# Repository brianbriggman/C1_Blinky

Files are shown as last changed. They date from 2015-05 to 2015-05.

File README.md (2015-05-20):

# C1_Blinky

The 'firmware' directory contains the firmware that gets flashed to the ATtiny85.  It can be re-built and re-flashed with a 'make clean' and 'make program'.

The 'commandline' directory contains the 'set-led' executable that sends R G B values to the 'C1_Blinky' connected to the USB port.  It can be re-built with a 'make clean' and 'make'.

Once compiled, you can execute 'set-led' using the format:  
  
	sudo ./set-led 255 0 0  
  
Where the 3 values following the 'set-led' command are the R(ed), G(reen), and B(lue) values respectively.  (The command above sets the C1 Blinky to full intensity red.)

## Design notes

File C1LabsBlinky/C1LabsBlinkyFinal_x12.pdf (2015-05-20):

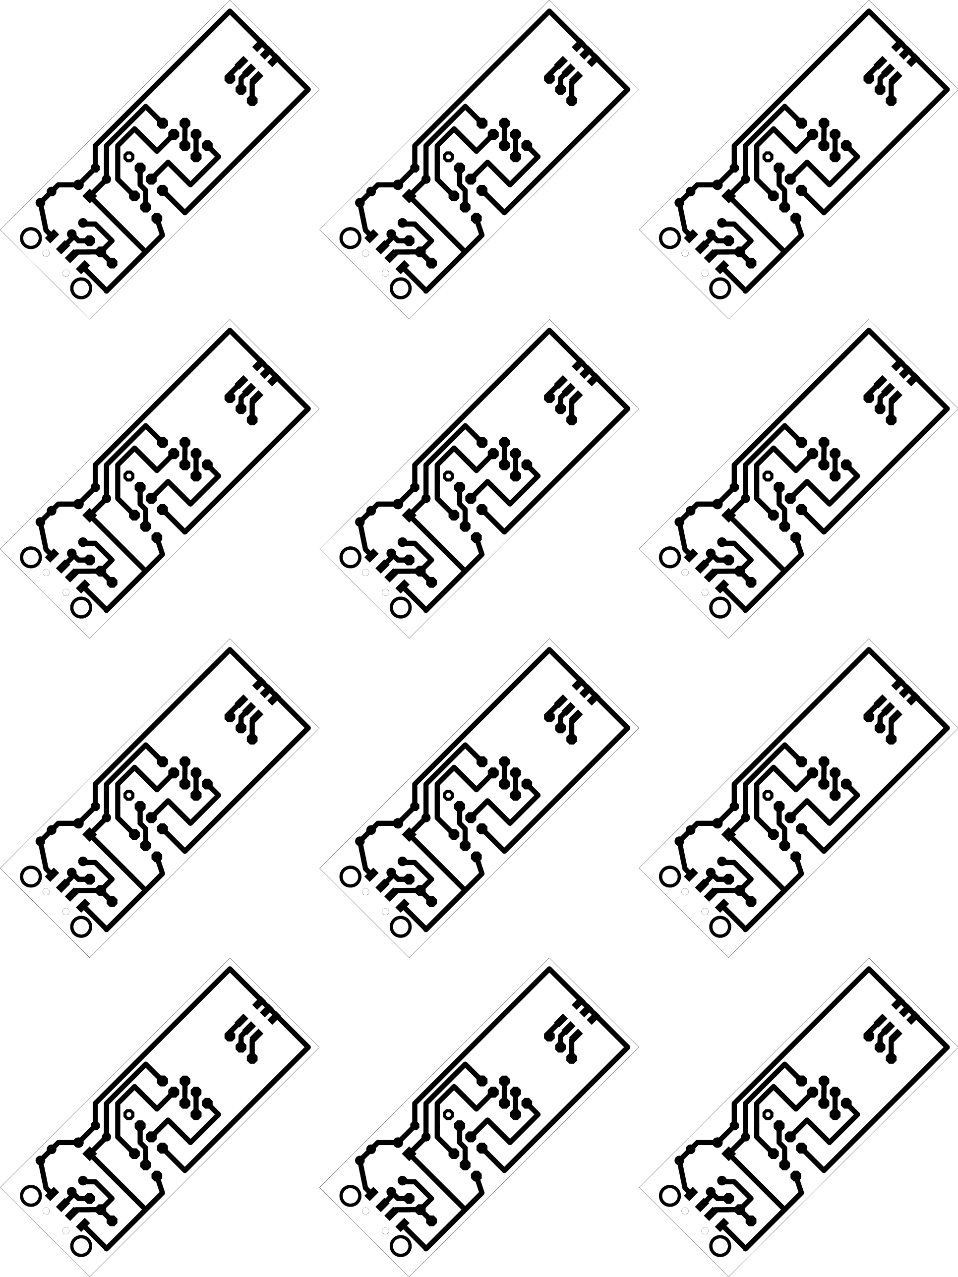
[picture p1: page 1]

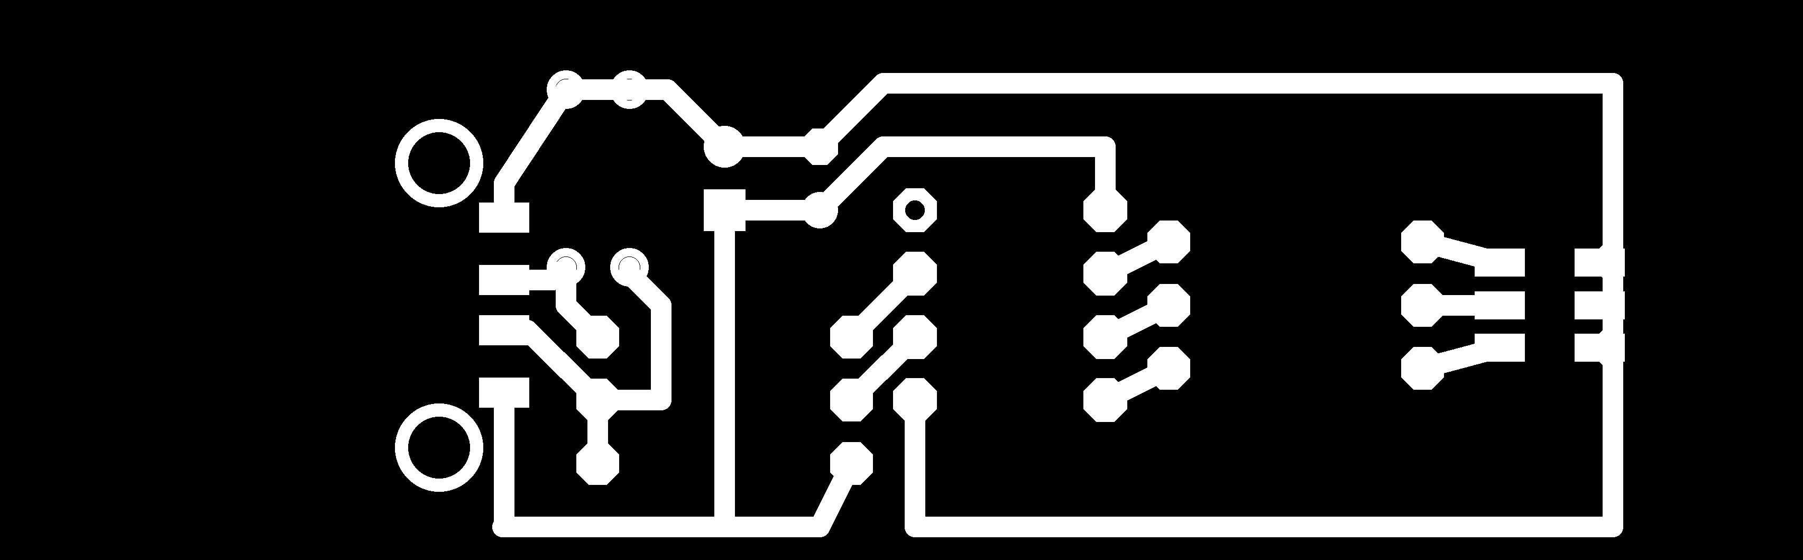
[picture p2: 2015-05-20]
C1LabsBlinky/pcb.png

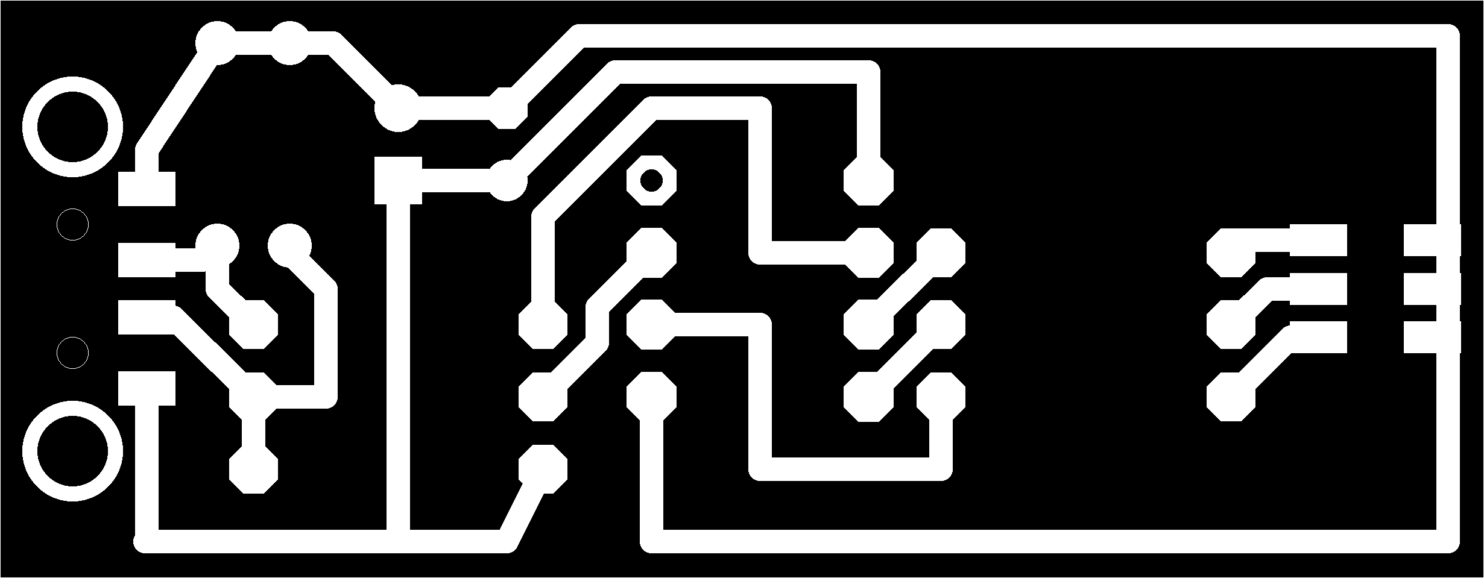
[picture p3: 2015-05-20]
C1LabsBlinky/C1LabsBlinkyFinal_out.png

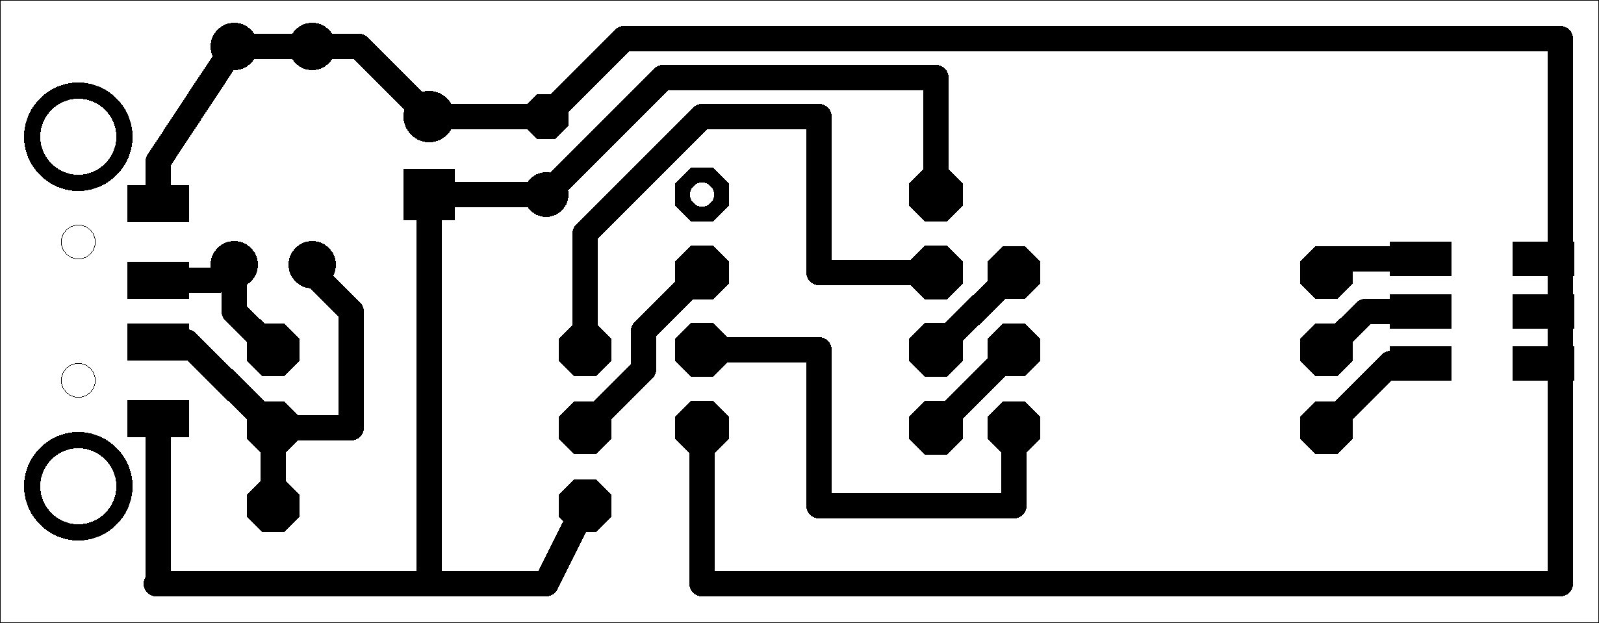
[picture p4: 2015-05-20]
C1LabsBlinky/C1LabsBlinkyFinal_out_pos.png

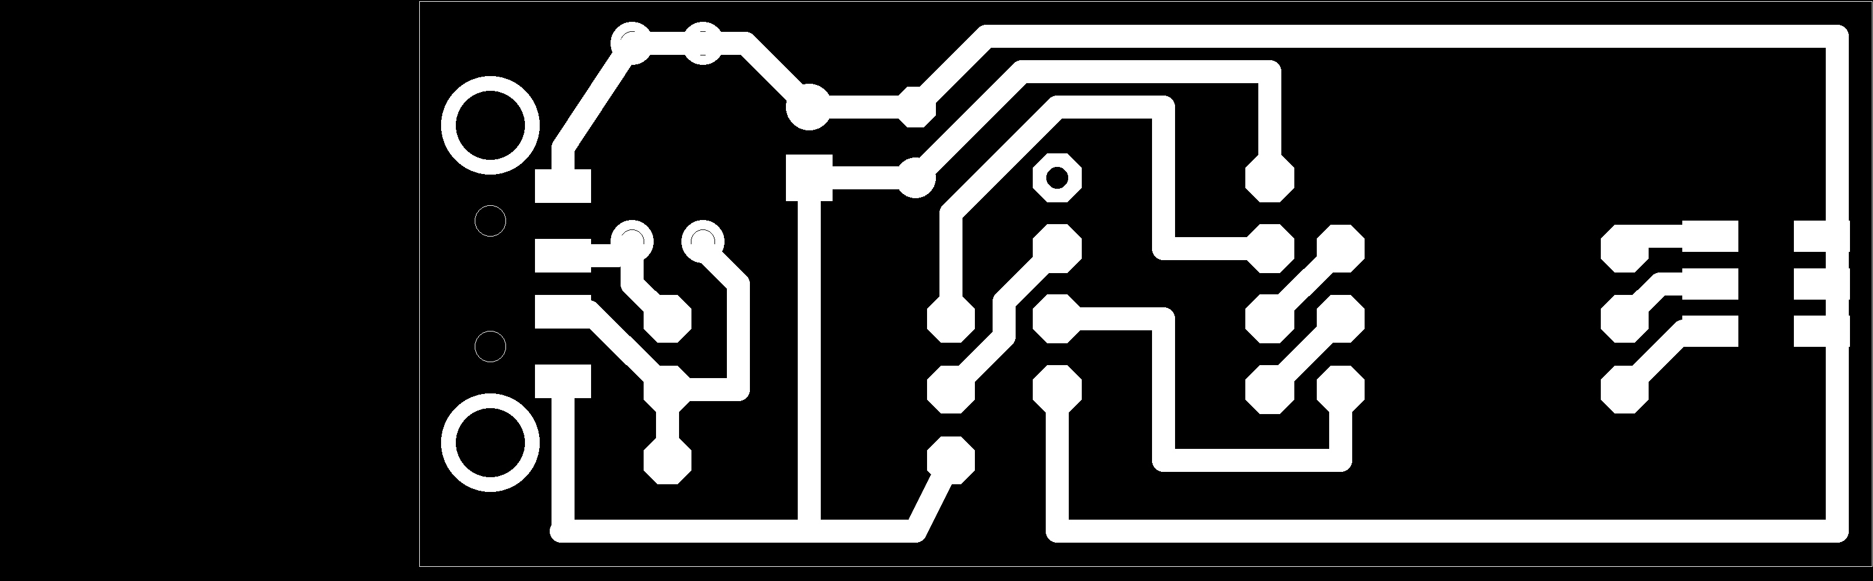
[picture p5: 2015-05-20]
C1LabsBlinky/C1LabsBlinkyFinal.png

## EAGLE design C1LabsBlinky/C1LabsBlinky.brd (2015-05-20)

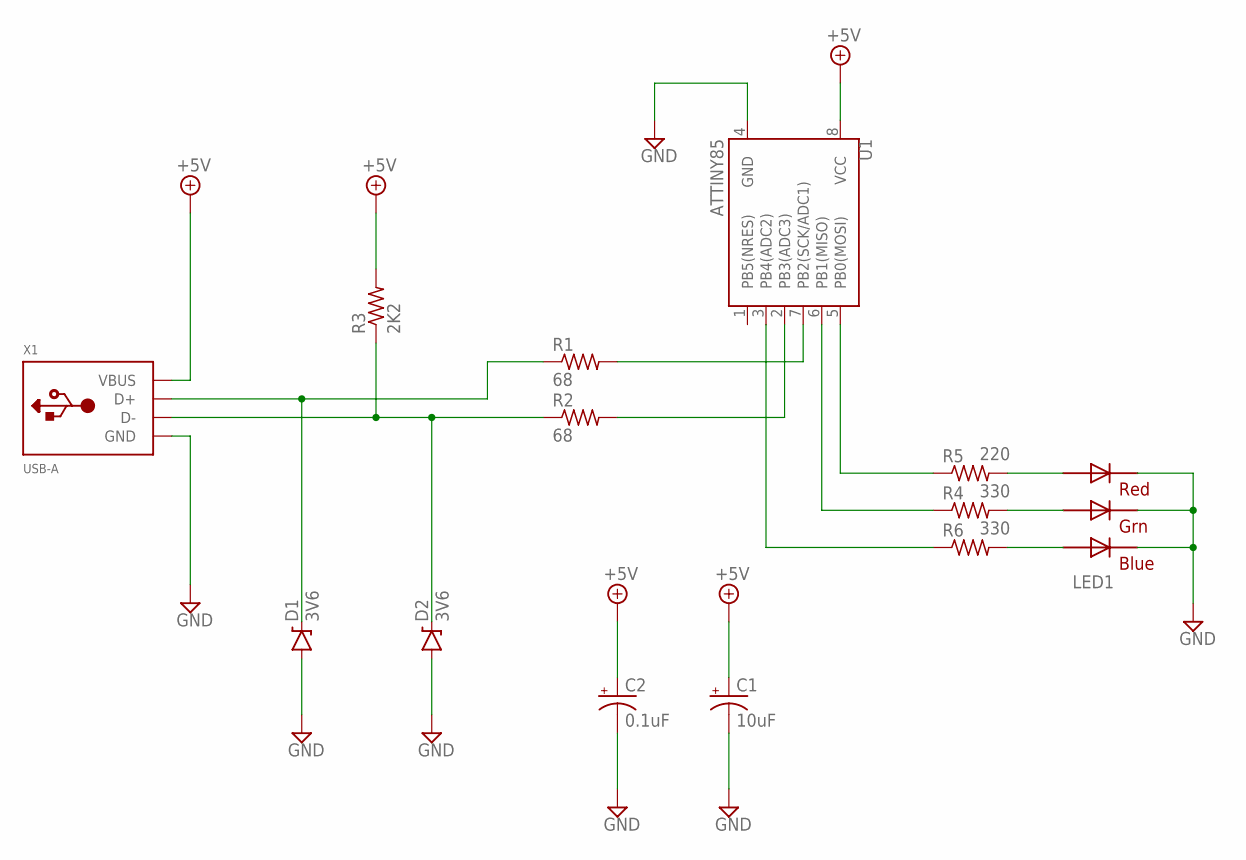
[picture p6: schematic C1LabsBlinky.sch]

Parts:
C1: 10uF; CPOL-RADIAL-10UF-25V
C2: 0.1uF; TT2D5
D1, D2: 3V6; DIODE-ZENER
LED1: RGBLED5050
R1, R2: 68; 0207/10
R3: 2K2; 0207/10
R4, R6: 330; 0207/10
R5: 220; 0207/10
U1: ATTINY85; DIP08
X1: USB-A; MOLEX_480371000

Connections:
+5V: C1.1 (+), C2.+, R3.2, U1.8 (VCC), X1.1 (VBUS)
GND: C1.2 (-), C2.-, D1.P$2 (A), D2.P$2 (A), LED1.4 (BLUE_C), LED1.5 (RED_C), LED1.6 (GREEN_C), U1.4 (GND), X1.4 (GND)
unnamed: D1.P$1 (C), R1.1, X1.3 (D+)
unnamed: D2.P$1 (C), R2.1, R3.1, X1.2 (D-)
unnamed: LED1.2 (RED_A), R5.2
unnamed: LED1.1 (GREEN_A), R4.2
unnamed: LED1.3 (BLUE_A), R6.2
unnamed: R5.1, U1.5 (PB0(MOSI))
unnamed: R1.2, U1.7 (PB2(SCK/ADC1))
unnamed: R4.1, U1.6 (PB1(MISO))
unnamed: R2.2, U1.2 (PB3(ADC3))
unnamed: R6.1, U1.3 (PB4(ADC2))

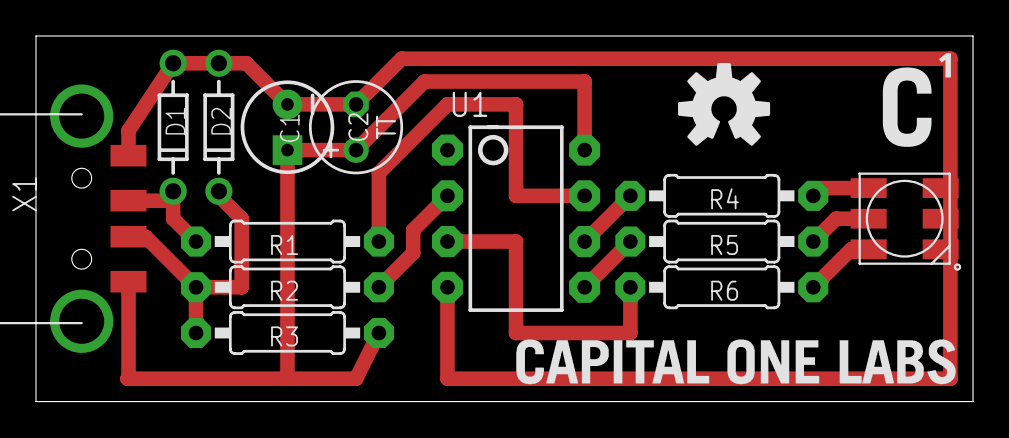
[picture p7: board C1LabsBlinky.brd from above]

Board: 2 copper layers, 52.1 x 20.3 mm, 16 parts (0 on the bottom side), 12 nets.

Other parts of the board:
U$1: C1_LABS_NAME_POS
U$2: OSHW-LOGO-M
U$3: C1_LABS_LOGO_S

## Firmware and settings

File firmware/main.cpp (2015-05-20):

/* Name: main.c
 * Project: hid-custom-rq example
 * Author: Christian Starkjohann
 * Creation Date: 2008-04-07
 * Tabsize: 4
 * Copyright: (c) 2008 by OBJECTIVE DEVELOPMENT Software GmbH
 * License: GNU GPL v2 (see License.txt), GNU GPL v3 or proprietary (CommercialLicense.txt)
 * This Revision: $Id: main.c 692 2008-11-07 15:07:40Z cs $
 */

/*
This example should run on most AVRs with only little changes. No special
hardware resources except INT0 are used. You may have to change usbconfig.h for
different I/O pins for USB. Please note that USB D+ must be the INT0 pin, or
at least be connected to INT0 as well.
We assume that an LED is connected to port B bit 0. If you connect it to a
different port or bit, change the macros below:
*/
#define LED_PORT_DDR        DDRB
#define LED_PORT_OUTPUT     PORTB
#define R_BIT            0
#define G_BIT            1
#define B_BIT            4


#include <avr/io.h>
#include <avr/wdt.h>
#include <avr/eeprom.h>
#include <avr/interrupt.h>  /* for sei() */
#include <util/delay.h>     /* for _delay_ms() */

#include <avr/pgmspace.h>   /* required by usbdrv.h */
extern "C"
{
	#include "usbdrv.h"
}
#include "oddebug.h"        /* This is also an example for using debug macros */
#include "requests.h"       /* The custom request numbers we use */

/* ------------------------------------------------------------------------- */
/* ----------------------------- USB interface ----------------------------- */
/* ------------------------------------------------------------------------- */

PROGMEM const char usbHidReportDescriptor[22] = {    /* USB report descriptor */
    0x06, 0x00, 0xff,              // USAGE_PAGE (Generic Desktop)
    0x09, 0x01,                    // USAGE (Vendor Usage 1)
    0xa1, 0x01,                    // COLLECTION (Application)
    0x15, 0x00,                    //   LOGICAL_MINIMUM (0)
    0x26, 0xff, 0x00,              //   LOGICAL_MAXIMUM (255)
    0x75, 0x08,                    //   REPORT_SIZE (8)
    0x95, 0x01,                    //   REPORT_COUNT (1)
    0x09, 0x00,                    //   USAGE (Undefined)
    0xb2, 0x02, 0x01,              //   FEATURE (Data,Var,Abs,Buf)
    0xc0                           // END_COLLECTION
};
/* The descriptor above is a dummy only, it silences the drivers. The report
 * it describes consists of one byte of undefined data.
 * We don't transfer our data through HID reports, we use custom requests
 * instead.
 */
static uint8_t count = 0;
static volatile uint8_t r = 0;
static volatile uint8_t g = 0;
static volatile uint8_t b = 0;
static uint8_t rb = 0;
static uint8_t gb = 0;
static uint8_t bb = 0;

/* ------------------------------------------------------------------------- */

extern "C" usbMsgLen_t usbFunctionSetup(uchar data[8])
{
	usbRequest_t    *rq = (usbRequest_t *)data;

    if((rq->bmRequestType & USBRQ_TYPE_MASK) == USBRQ_TYPE_VENDOR)
	{
		switch(rq->bRequest)
		{
		case CUSTOM_RQ_SET_RED:
			r = rq->wValue.bytes[0];
			break;	
		case CUSTOM_RQ_SET_GREEN:
			g = rq->wValue.bytes[0];
			break;	
		case CUSTOM_RQ_SET_BLUE:
			b = rq->wValue.bytes[0];
			break;	
		}
    }
	else
	{
        /* class requests USBRQ_HID_GET_REPORT and USBRQ_HID_SET_REPORT are
         * not implemented since we never call them. The operating system
         * won't call them either because our descriptor defines no meaning.
         */
    }
    return 0;   /* default for not implemented requests: return no data back to host */
}

static void calibrateOscillator(void)
{
uchar       step = 128;
uchar       trialValue = 0, optimumValue;
int         x, optimumDev, targetValue = (unsigned)(1499 * (double)F_CPU / 10.5e6 + 0.5);
 
    /* do a binary search: */
    do{
        OSCCAL = trialValue + step;
        x = usbMeasureFrameLength();    // proportional to current real frequency
        if(x < targetValue)             // frequency still too low
            trialValue += step;
        step >>= 1;
    }while(step > 0);
    /* We have a precision of +/- 1 for optimum OSCCAL here */
    /* now do a neighborhood search for optimum value */
    optimumValue = trialValue;
    optimumDev = x; // this is certainly far away from optimum
    for(OSCCAL = trialValue - 1; OSCCAL <= trialValue + 1; OSCCAL++){
        x = usbMeasureFrameLength() - targetValue;
        if(x < 0)
            x = -x;
        if(x < optimumDev){
            optimumDev = x;
            optimumValue = OSCCAL;
        }
    }
    OSCCAL = optimumValue;
}
 

extern "C" void usbEventResetReady(void)
{
    cli();  // usbMeasureFrameLength() counts CPU cycles, so disable interrupts.
    calibrateOscillator();
    sei();
    eeprom_write_byte(0, OSCCAL);   // store the calibrated value in EEPROM
}

/* ------------------------------------------------------------------------- */
void update_leds()
{
  if (++count == 0) {    
    rb = r;
    gb = g;
    bb = b;
    // check if switch on r, g and b
    if (rb > 0) {        
      PORTB |= (1 << R_BIT);
    } 
    if (gb > 0) {
      PORTB |= (1 << G_BIT);
    } 
    if (bb > 0) {
      PORTB |= (1 << B_BIT);
    } 
  }
  // check if switch off r, g and b
  if (count == rb) {     
    PORTB &= ~(1 << R_BIT);
  }
  if (count == gb) {
    PORTB &= ~(1 << G_BIT);
  }
  if (count == bb) {
    PORTB &= ~(1 << B_BIT);
  }
}

void update_leds2()
{
    /* PWM enable,  */
    GTCCR |= _BV(PWM1B) | _BV(COM1B1);

    TCCR0A |= _BV(WGM00) | _BV(WGM01) | _BV(COM0A1) | _BV(COM0B1);

    /* Start timer 0 and 1 */
    TCCR1 |= _BV(CS10);

    TCCR0B |=  _BV(CS00);

    /* Set PWM value to 0. */
    OCR0A = 255;   // PB0
    OCR0B = 255;   // PB1
    OCR1B = 255;   // PB4
}

int main(void)
{
	uchar   i;

    wdt_enable(WDTO_1S);
    /* Even if you don't use the watchdog, turn it off here. On newer devices,
     * the status of the watchdog (on/off, period) is PRESERVED OVER RESET!
     */
    /* RESET status: all port bits are inputs without pull-up.
     * That's the way we need D+ and D-. Therefore we don't need any
     * additional hardware initialization.
     */

    usbInit();
    usbDeviceDisconnect();  /* enforce re-enumeration, do this while interrupts are disabled! */
    i = 0;
    while(--i){             /* fake USB disconnect for > 250 ms */
        wdt_reset();
        _delay_ms(1);
    }
    usbDeviceConnect();
    LED_PORT_DDR |= _BV(R_BIT);   /* make the LED bit an output */
    LED_PORT_DDR |= _BV(G_BIT);   /* make the LED bit an output */
    LED_PORT_DDR |= _BV(B_BIT);   /* make the LED bit an output */
	
    sei();

    for(;;){                /* main event loop */
		update_leds();
		
        wdt_reset();
        usbPoll();
    }
    return 0;
}

/* ------------------------------------------------------------------------- */

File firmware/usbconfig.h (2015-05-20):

/* Name: usbconfig.h
 * Project: AVR USB driver
 * Author: Christian Starkjohann
 * Creation Date: 2005-04-01
 * Tabsize: 4
 * Copyright: (c) 2005 by OBJECTIVE DEVELOPMENT Software GmbH
 * License: GNU GPL v2 (see License.txt), GNU GPL v3 or proprietary (CommercialLicense.txt)
 * This Revision: $Id: usbconfig-prototype.h 692 2008-11-07 15:07:40Z cs $
 */

#ifndef __usbconfig_h_included__
#define __usbconfig_h_included__


#ifndef __ASSEMBLER__
extern void usbEventResetReady(void);
#endif
#define USB_RESET_HOOK(isReset)         if(!isReset){usbEventResetReady();}

/*
General Description:
This file is an example configuration (with inline documentation) for the USB
driver. It configures AVR-USB for USB D+ connected to Port D bit 2 (which is
also hardware interrupt 0 on many devices) and USB D- to Port D bit 4. You may
wire the lines to any other port, as long as D+ is also wired to INT0 (or any
other hardware interrupt, as long as it is the highest level interrupt, see
section at the end of this file).
*/

/* ---------------------------- Hardware Config ---------------------------- */

#define USB_CFG_IOPORTNAME      B
/* This is the port where the USB bus is connected. When you configure it to
 * "B", the registers PORTB, PINB and DDRB will be used.
 */
#define USB_CFG_DMINUS_BIT      3
/* This is the bit number in USB_CFG_IOPORT where the USB D- line is connected.
 * This may be any bit in the port.
 */
#define USB_CFG_DPLUS_BIT       2
/* This is the bit number in USB_CFG_IOPORT where the USB D+ line is connected.
 * This may be any bit in the port. Please note that D+ must also be connected
 * to interrupt pin INT0! [You can also use other interrupts, see section
 * "Optional MCU Description" below, or you can connect D- to the interrupt, as
 * it is required if you use the USB_COUNT_SOF feature. If you use D- for the
 * interrupt, the USB interrupt will also be triggered at Start-Of-Frame
 * markers every millisecond.]
 */
#define USB_CFG_CLOCK_KHZ       (F_CPU/1000)
/* Clock rate of the AVR in MHz. Legal values are 12000, 12800, 15000, 16000,
 * 16500 and 20000. The 12.8 MHz and 16.5 MHz versions of the code require no
 * crystal, they tolerate +/- 1% deviation from the nominal frequency. All
 * other rates require a precision of 2000 ppm and thus a crystal!
 * Default if not specified: 12 MHz
 */

/* ----------------------- Optional Hardware Config ------------------------ */

/* #define USB_CFG_PULLUP_IOPORTNAME   D */
/* If you connect the 1.5k pullup resistor from D- to a port pin instead of
 * V+, you can connect and disconnect the device from firmware by calling
 * the macros usbDeviceConnect() and usbDeviceDisconnect() (see usbdrv.h).
 * This constant defines the port on which the pullup resistor is connected.
 */
/* #define USB_CFG_PULLUP_BIT          4 */
/* This constant defines the bit number in USB_CFG_PULLUP_IOPORT (defined
 * above) where the 1.5k pullup resistor is connected. See description
 * above for details.
 */

/* --------------------------- Functional Range ---------------------------- */
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

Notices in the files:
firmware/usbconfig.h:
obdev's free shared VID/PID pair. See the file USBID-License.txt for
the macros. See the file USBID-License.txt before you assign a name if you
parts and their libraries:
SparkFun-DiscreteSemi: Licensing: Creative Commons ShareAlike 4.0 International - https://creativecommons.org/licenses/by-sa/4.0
